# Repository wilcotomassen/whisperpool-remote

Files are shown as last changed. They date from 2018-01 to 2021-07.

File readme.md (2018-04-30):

# Whisper Pool remote replacement

> TLDR: Whirlpool remote didn't work. I replaced it with an Arduino
> based remote that sent out the same [RC5](https://en.wikipedia.org/wiki/RC-5) remote 
> commands using this [Arduino IR-Remote library](https://github.com/z3t0/Arduino-IRremote).
>
> You can find the code [here](firmware) and the schematics and
> pcb design [here](hardware)
>
> I think this same solution should work for following whirlpools from Villeroy & Boch:
> 
> * Whisper Airpool
> * Clairpool
> * Whisper Whirlpool
> * Whisper Combipool

## The problem with the remote

Our home has a Villeroy and Boch whirlpool installed and after about half a 
year after we moved in and about three uses, the remote stopped functioning.

Opening the battery compartment made the cause cleary very quickly. The batteries
started leaking and (probably) deposited their acidic schmoo all over the pcb, 
corriding it and the components. As the remote enclosure is water proof and seems
to be glued together, there was no easy way to clean it. After trying to rinse it
out with some household chemicals through the battery compartment, it still didn't 
work.

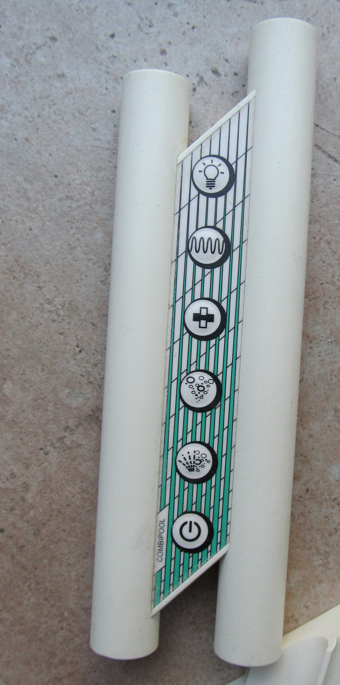
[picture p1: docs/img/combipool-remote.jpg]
The offending remote (picture from the web)


There are replacement remotes availble, but they are about 150 euros. I like a 
working whirlpool, but not that much. So I decided to tear it down and see if there
was a likely fix.

## Teardown an protocol identification

There was no easy way to open the remote enclosure (because it's water proof), 
so I ended up cracking it open with pliers to get to in. Inside there's 
pretty much what one would expect, a tube to act as the battery compartment, a
small PCB in the middle doing the logic and an IR led to send the commands.

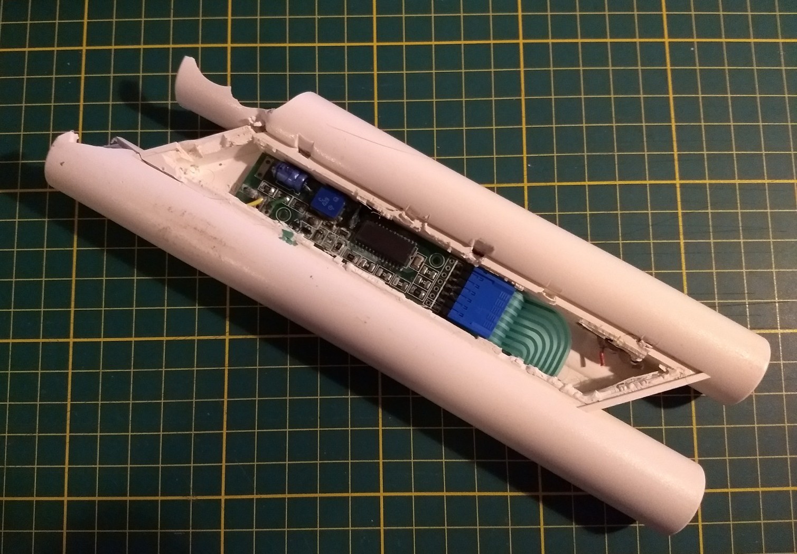
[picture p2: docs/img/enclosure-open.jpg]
The enclosure, delicately opened


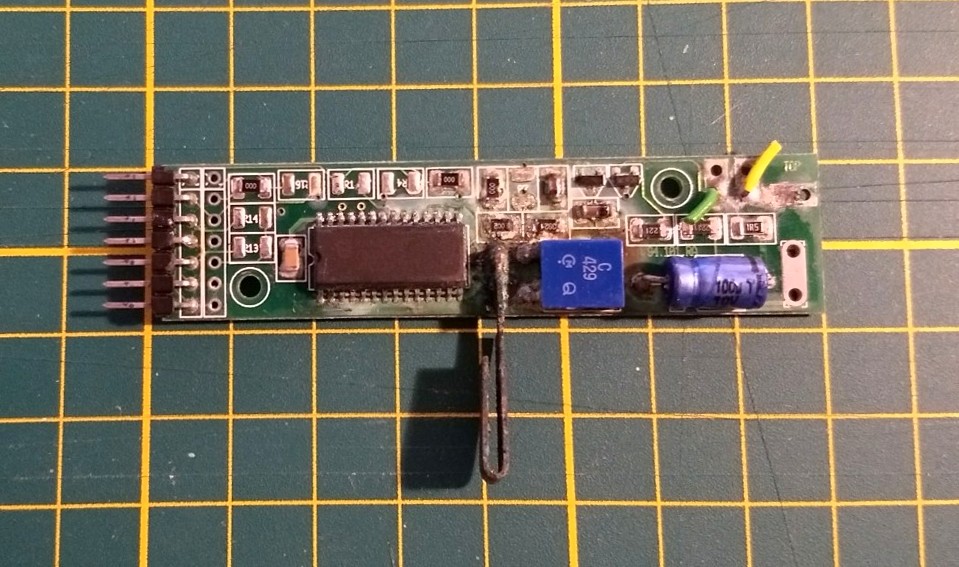
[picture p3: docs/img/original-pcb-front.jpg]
The PCB - Front


> As you can see there's quite a bit of corrosion on the PCB, either from moisture
> or from battery acid. Cleaning it with some isopropyl alcohol might salvage this, but
> I opted to toss it, rather that attempt that. The cut leads are from the IR led.

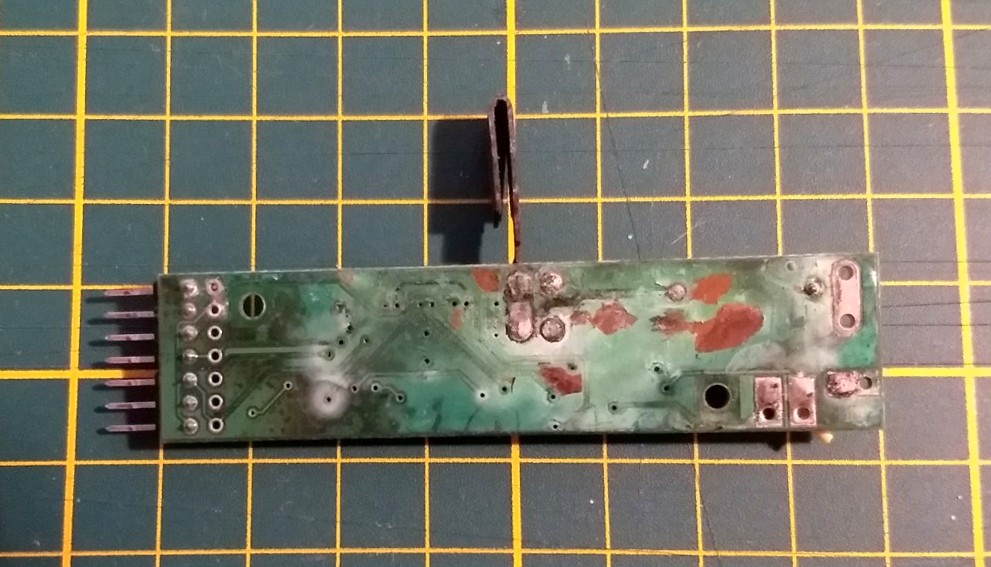
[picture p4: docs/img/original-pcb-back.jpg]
The PCB - Back


### RC5 transmitter IC

The main attraction on the PCB is the Philips/NXP IC, which is an RC5 Infrared 
remote control transmitter that does pretty much everything on the board. 

These markings are printet on the chip, next to the Philips logo:

> **SAA3010T**  
> **79030C**  
> **US0211 2 Y**  

The data sheet can be found [here](docs/SAA3010T-datasheet.pdf)

The chip handles the scanning of the remote buttons, and converting those into
valid [RC5 protocol](https://en.wikipedia.org/wiki/RC-5) commands and sending 
them out into the world via the IR led.

The [datasheet](SAA3010T-datasheet.pdf) explains how the key scan combinations
are converted into the RC5 address and command bits, so there's no code that
runs on the IC for this specific remote; all the information for the commands
is in the connections on the PCB (which is good, because I cannot capture the 
RC commands from a non-working remote).

### RC5 protocol parts

A command in the RC5 protocol is composed of 

* One start bit (fixed value of 1)
* One field bit (fixed value of 1)
* One control bit (toggled between commands)
* Five address bits (to set the system type, e.g. TV, VCR, etc)
* Six command bits (the actual command)

more information [here](https://en.wikipedia.org/wiki/RC-5)

We need to figure out the address and command bits to make a working
remote.

### Address bits

Finding the correct address bits was as simple as finding which Z- and 
DR lines from the IC were connected on the PCB. They turned out to be
Z3 (pin 6) and DR7 (pin 9). From the System matrix in the datasheet on
page 10, this dermines the system number 31 (a reserved system number), 
which has these system bits: ```11111```. 

### Command bits (via key scanning)

With a multimeter I checked how the buttons wires corresponded to the pins on the 
RC5 IC. It turns out that one wire was connected to the X5 pin and all the other
pins to 6 DR-lines.

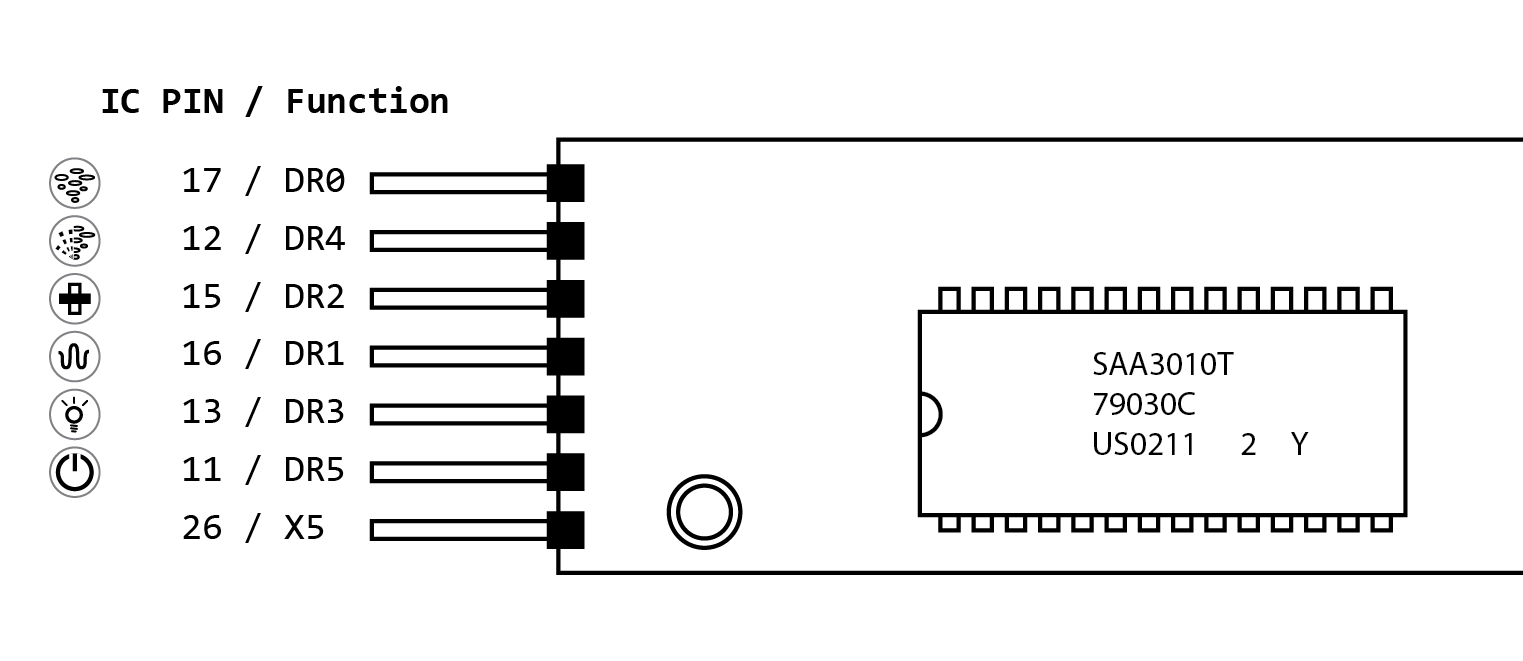
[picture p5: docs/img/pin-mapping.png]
Pin mapping of the button connector


When a buttons is pressed, it connects on of the DR pins to the X5 pin. The datasheet 
contains a nice table on page 9 to lookup the command bits for those X/DR combinations.

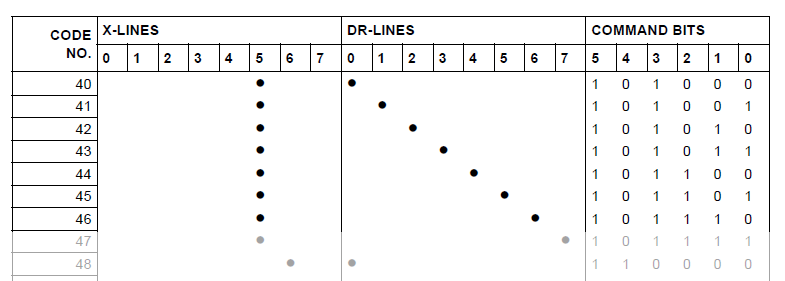
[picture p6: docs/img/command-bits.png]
Excerpt from the Command bits lookup table (data sheet page 9)


### Complete commands

| Button | Code | Start bit | Field bit | Control bit | Address bits | Command bits | => | Complete command | 
|---|---|---|---|---|---|---|:--:|---:|
|  | 40 | 1 | 1 | 1/0 | 11111 | 101000 | => | 11111111101000 |
|  | 41 | 1 | 1 | 1/0 | 11111 | 101001 | => | 11111111101001 |
|  | 42 | 1 | 1 | 1/0 | 11111 | 101010 | => | 11111111101010 |
|  | 43 | 1 | 1 | 1/0 | 11111 | 101011 | => | 11111111101011 |
|  | 44 | 1 | 1 | 1/0 | 11111 | 101100 | => | 11111111101100 |
|  | 45 | 1 | 1 | 1/0 | 11111 | 101101 | => | 11111111101101 |

## The replacement

Once the protocol was found, it was fairly easy to find an Arduino library that 
was able to send out RC5 commands: [Arduino IR-Remote](https://github.com/z3t0/Arduino-IRremote)

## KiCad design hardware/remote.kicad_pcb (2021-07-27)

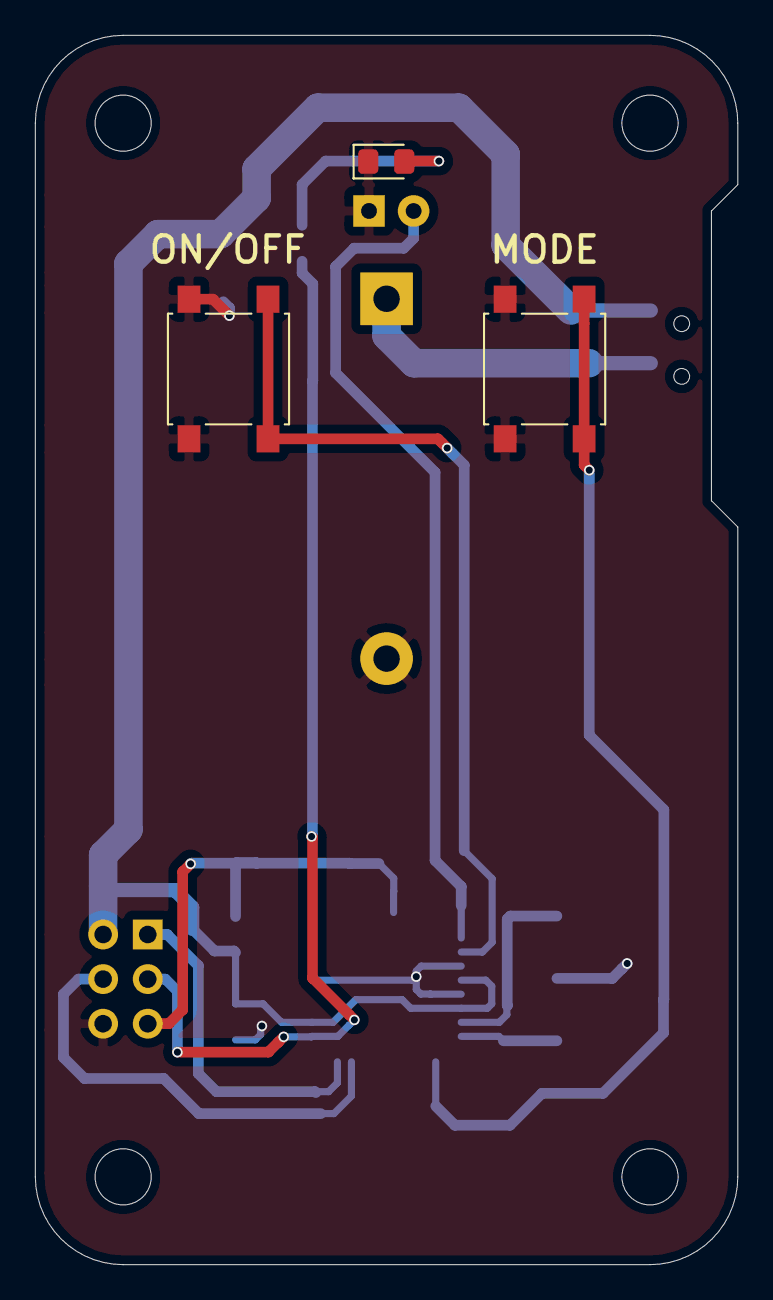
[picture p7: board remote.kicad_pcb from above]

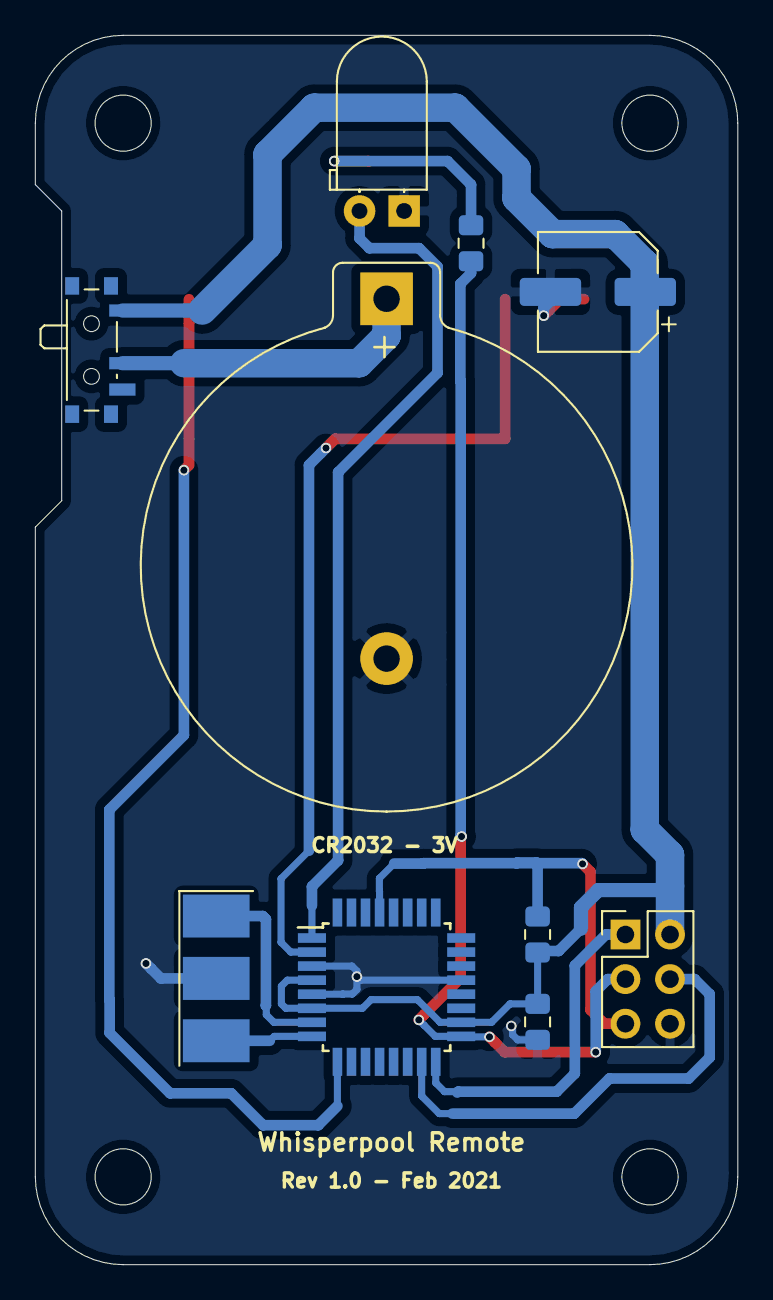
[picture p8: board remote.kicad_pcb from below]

Board: 2 copper layers, 40.0 x 70.0 mm, 17 parts (10 on the bottom side), 13 nets.

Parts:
BT1: Battery_Cell; BatteryHolder_Keystone_107_1x23mm
C1: C_Small; C_0805_2012Metric_Pad1.15x1.40mm_HandSolder
C2: CP_Small; CP_Elec_6.3x4.5
D1: LED; LED_D5.0mm_Horizontal_O1.27mm_Z3.0mm_IRBlack
D2: LED; LED_0805_2012Metric_Pad1.15x1.40mm_HandSolder
H1, H2, H3, H4: MountingHole; MountingHole_3.2mm_M3
J1: AVR-ISP-6; PinHeader_2x03_P2.54mm_Vertical
MODE: SW_Push; SW_SPST_B3S-1000
ON/OFF: SW_Push; SW_SPST_B3S-1000
R1, R2: R_Small; R_0805_2012Metric_Pad1.15x1.40mm_HandSolder
SW1: SW_SPDT; SW_SPDT_PCM12
U1: ATMEGA328-AU; TQFP-32_7x7mm_P0.8mm
Y1: Resonator_Small; Resonator_SMD-3Pin_7.2x3.0mm_HandSoldering

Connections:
BTN1: ON/OFF.2, U1.2
BTN2: MODE.2, U1.9
GND: BT1.2, C1.2, C2.2, D1.1, D2.1, J1.6, MODE.1, ON/OFF.1, U1.3, U1.5, U1.21, Y1.2
LED_INFO: J1.3, R1.2, U1.17
LED_IR: D1.2, U1.1
MISO: J1.1, U1.16
MOSI: J1.4, U1.15
unnamed: BT1.1, SW1.2
unnamed: D2.2, R1.1
unnamed: U1.7, Y1.1
unnamed: U1.8, Y1.3
RST: J1.5, R2.2, U1.29
VCC: C1.1, C2.1, J1.2, R2.1, SW1.1, U1.4, U1.6, U1.18

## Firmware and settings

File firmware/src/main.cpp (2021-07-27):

#include <avr/sleep.h>
#include <avr/power.h>
#include <Arduino.h>

#define SEND_PWM_BY_TIMER
#include <IRremote.h>

// Input pin configuration
#define BTN_1     4
#define BTN_2     5

// Output pin configuration
#define LED_IR    3 // Required on this pin by the IRremote library 
#define LED_ACT   13

// Relevant RC5 codes
#define CODE_40 0b1101111110100000 // Bubbles
#define CODE_41 0b1101111110100100 // Standing waves
#define CODE_42 0b1101111110101000 // Plus
#define CODE_43 0b1101111110101100 // Light
#define CODE_44 0b1101111110110000 // Combination
#define CODE_45 0b1101111110110100 // On/Off
#define CC_MASK 0b0010000000000000 // Command bit mask

IRsend sender;

// Data properties
int nextMode = 0;
bool flipCommandBit = false;

void pciSetup(byte pin) {
    *digitalPinToPCMSK(pin) |= bit (digitalPinToPCMSKbit(pin));  // enable pin
    PCIFR  |= bit (digitalPinToPCICRbit(pin)); // clear any outstanding interrupt
    PCICR  |= bit (digitalPinToPCICRbit(pin)); // enable interrupt for the group
}

void blink(uint8_t blinkCount) {
  for (uint8_t i = 0; i < blinkCount; i++) {
      digitalWrite(LED_ACT, HIGH);
      delay(100);
      digitalWrite(LED_ACT, LOW);
      delay(100);
  }
}

void wakeUp() {

  // Stop sleeping
  sleep_disable();

}

void doSleep() {

  // Sleep
  sleep_enable();
  set_sleep_mode(SLEEP_MODE_PWR_DOWN);

  // Turn off brown-out enable in software
  MCUCR = bit (BODS) | bit (BODSE);
  MCUCR = bit (BODS); 
  interrupts ();  // guarantees next instruction executed
  sleep_cpu();

}

void sendCode(unsigned long data) {

  // Light notification LED
  digitalWrite(LED_ACT, HIGH);

  // // Flip command bit if required, and flip command bit
  // if (flipCommandBit) {
  //   data |= CC_MASK;
  // }
  // flipCommandBit = !flipCommandBit;

  // Send code
  sender.sendRC5(data, 14);
  delay(113);

  // Dim notification LED
  digitalWrite(LED_ACT, LOW);
  
}

void setup() {

  // Setup button pins
  pinMode(BTN_1, INPUT_PULLUP);
  pciSetup(BTN_1);

  pinMode(BTN_2, INPUT_PULLUP);
  pciSetup(BTN_2);  

  pinMode(LED_IR, OUTPUT);
  pinMode(LED_ACT, OUTPUT);
  
  // Disable unused AVR modules 
  //power_all_disable();
  //power_timer0_enable(); // Need timer0 for delay

}

void loop() {
  
  // Attempt to read buttons
  for (uint8_t i = 0; i < 10; i++) {

    // On/Off
    if (!digitalRead(BTN_1)) {
      sendCode(CODE_45);
    } 
    
    // Mode
    if (!digitalRead(BTN_2)) {
      
      switch(nextMode) {
        case 0:
          sendCode(CODE_40);
          break;
        case 1:
          sendCode(CODE_41);
          break;
        case 2:
          sendCode(CODE_42);
          break;
        case 3:
          sendCode(CODE_43);
          break;
        case 4:
          sendCode(CODE_44);
          break;
      }

      // Increment mode
      if (nextMode == 4) {
        nextMode = 0;
      } else {
        nextMode++;
      }
      
    }

    delay(10);

  }

  // No action found, so sleep
  doSleep();

}

ISR (PCINT2_vect) {
  // No method body needed, just need to wake up by PCINT
}  

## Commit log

2018-01-18 Updated pin
2018-01-18 Added button images
2018-04-21 Added kicad hardware design
    [remote.kicad_pcb, remote.sch]
2018-04-30 Cleaned up code, added fuses
2018-04-30 Added image files from original PCB
2018-04-30 Added original pcb images to the readme
2019-10-21 Update to Kicad 5
    [remote.sch]
2021-07-27 Hardware update
    [remote.kicad_pcb, remote.sch]
